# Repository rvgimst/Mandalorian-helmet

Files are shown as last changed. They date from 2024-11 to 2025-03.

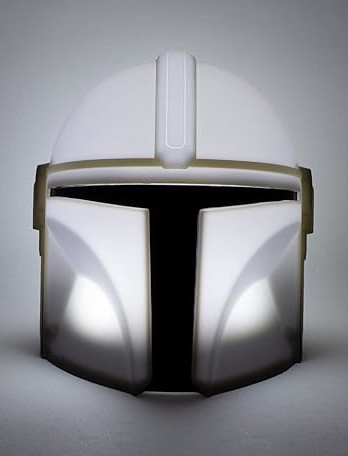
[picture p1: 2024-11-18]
pics/Mando helmet light on.jpg

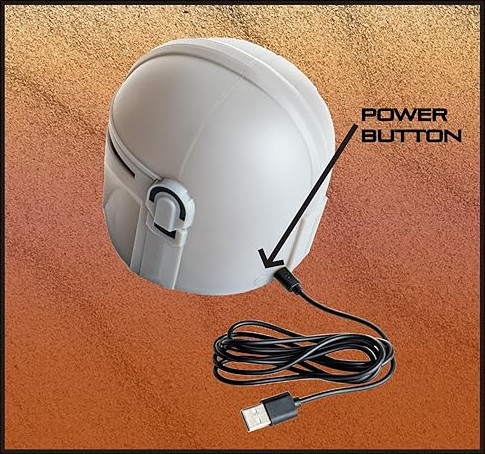
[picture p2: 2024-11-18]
pics/Mando helmet back.jpg

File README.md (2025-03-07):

# Mandalorian-helmet
Project to create a 3D printed mano helmet and add sounds and lights to it using Arduino with LEDs

Used ideas and files from:
https://www.myminifactory.com/object/3d-print-mandalorian-helmet-v2-106137

https://all3dp.com/2/3d-printed-mandalorian-helmet-3d-models/

Note on hardware I used:
========================
I used an Arduino Nano Every which worked fine on the breadboard, powered through its micro-USB port and the 5V pin connected to the breadboard's power strip (Vin not used).
When soldered on a protoboard in the device, the Arduino is powered through the Vin pin (5V pin not used).
When trying to connect the micro-USB port to the PCs USB port for uploading the code to the Arduino, it didn't work. Turns out that the Arduino powers the Vin port (which powers the MP player and all other components) and that it fails the PC to even recognize the Arduino. When ALSO powered through the power input of the device (Mando helmet), uploading worked!

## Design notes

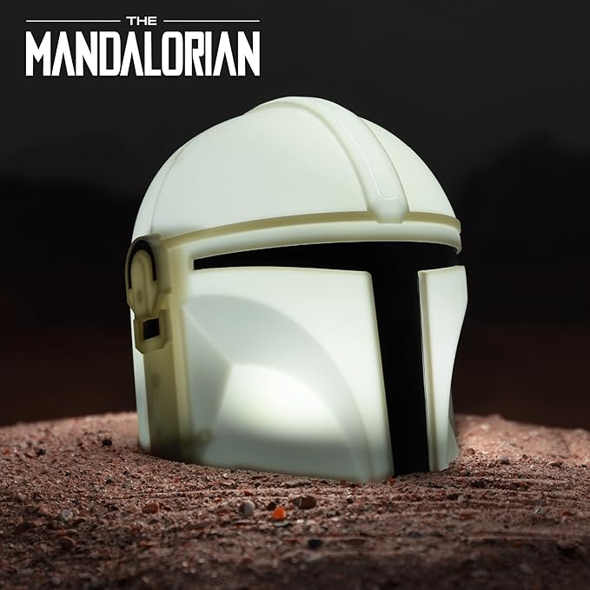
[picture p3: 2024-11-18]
pics/The Mandalorian Helmet Light.jpg

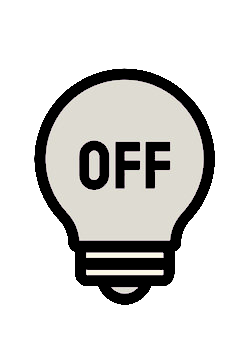
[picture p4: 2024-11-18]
pics/lamp off1.png

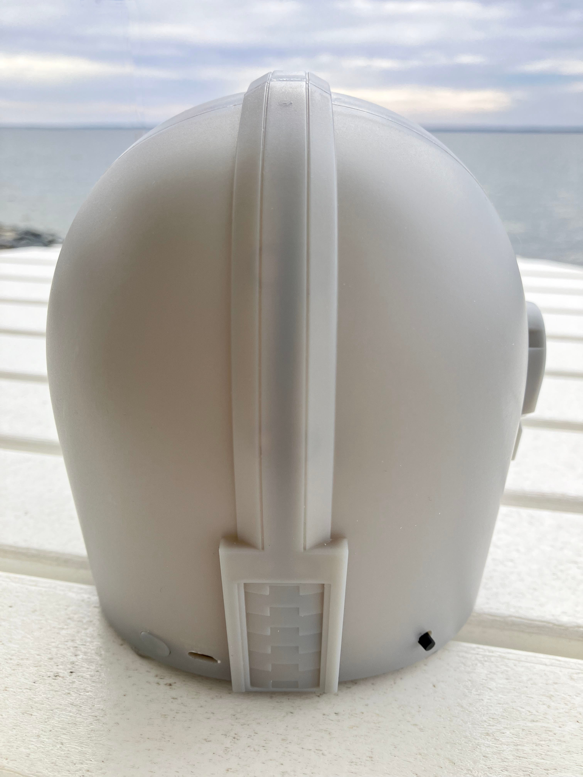
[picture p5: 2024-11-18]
pics/mando helmet rear.jpg

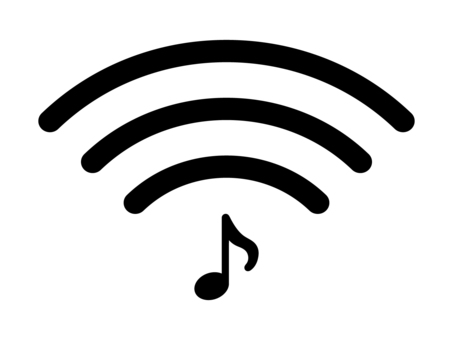
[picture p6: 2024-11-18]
pics/soundwave.jpeg

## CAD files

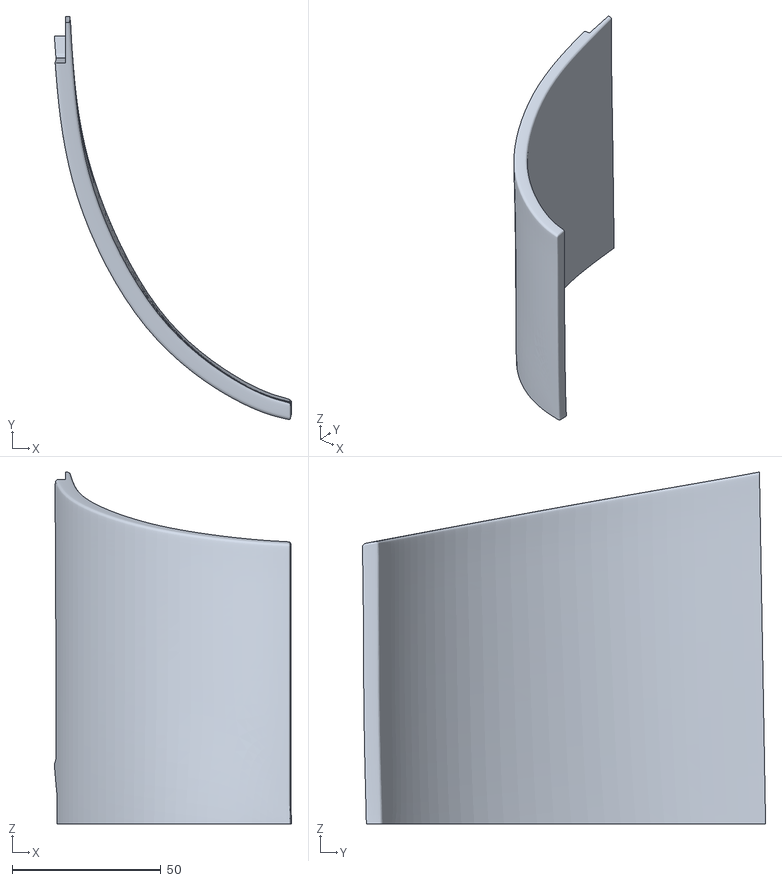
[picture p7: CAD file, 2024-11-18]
Mando helmet/helmet-8-piece-right-back-bottom.stl
79.9 x 135.7 x 118.5

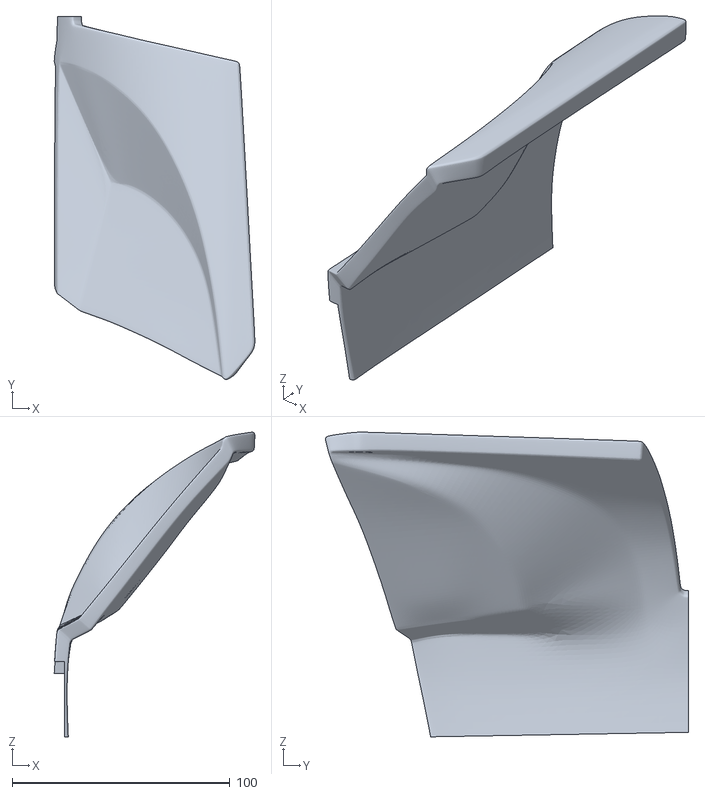
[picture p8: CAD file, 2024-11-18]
Mando helmet/helmet-8-piece-right-front-bottom.stl
92.2 x 166.8 x 140.0

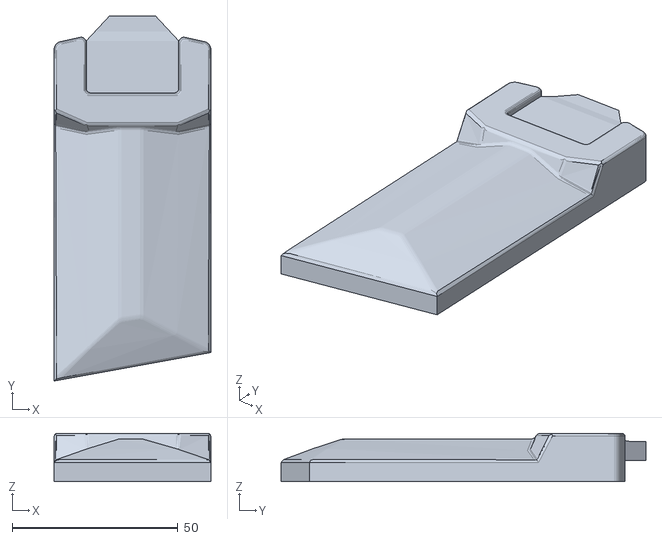
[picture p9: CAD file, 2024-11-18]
Mando helmet/ear-left-bottom.stl
47.3 x 110.2 x 14.6

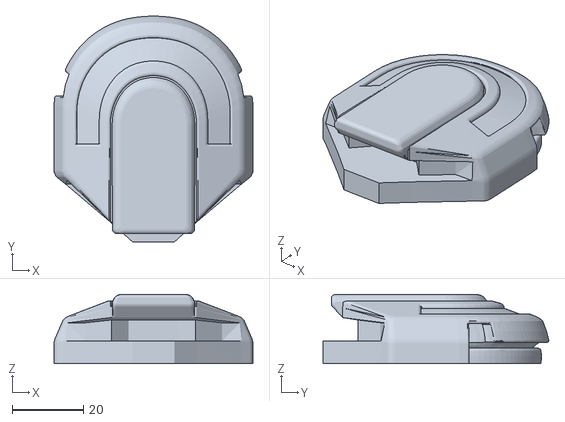
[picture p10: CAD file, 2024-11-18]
Mando helmet/ear-right-top.stl
56.0 x 63.5 x 19.5

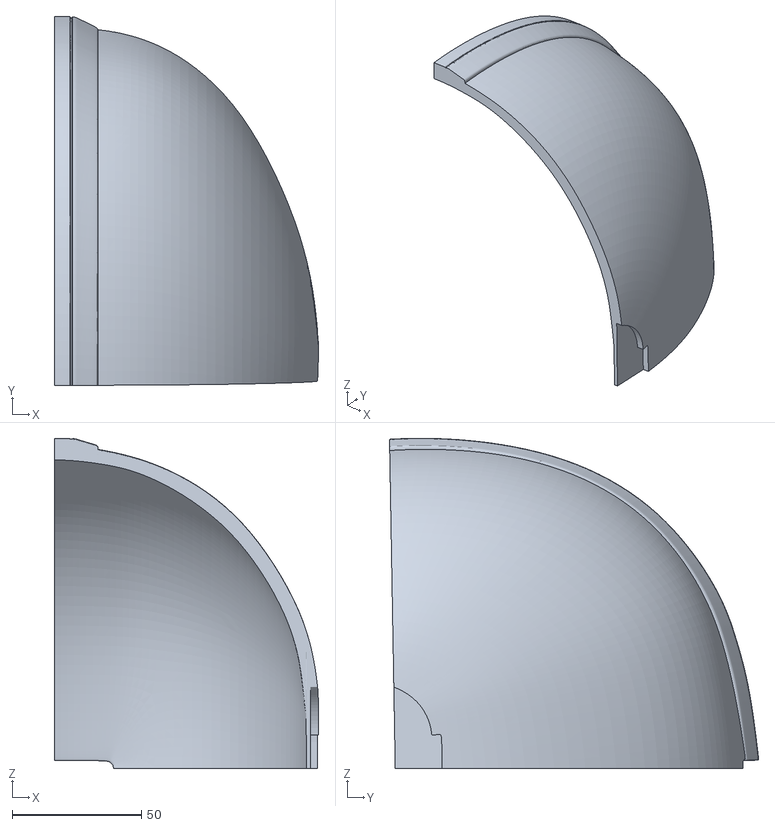
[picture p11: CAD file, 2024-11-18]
Mando helmet/helmet-8-piece-left-back-top.stl
102.3 x 142.7 x 127.8

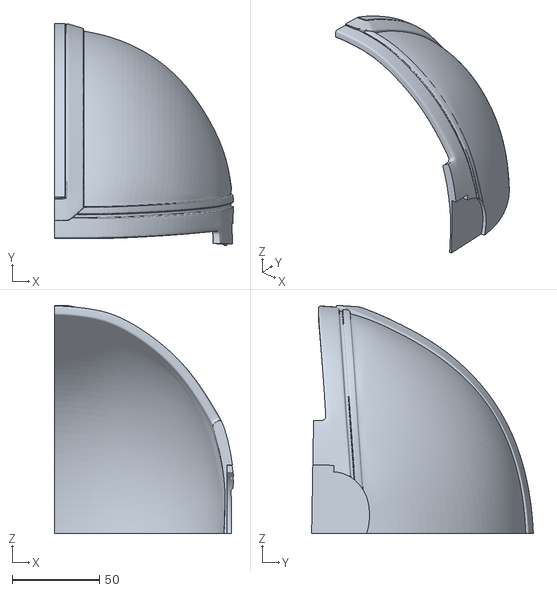
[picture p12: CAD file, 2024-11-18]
Mando helmet/helmet-8-piece-left-front-top.stl
103.0 x 127.4 x 131.0

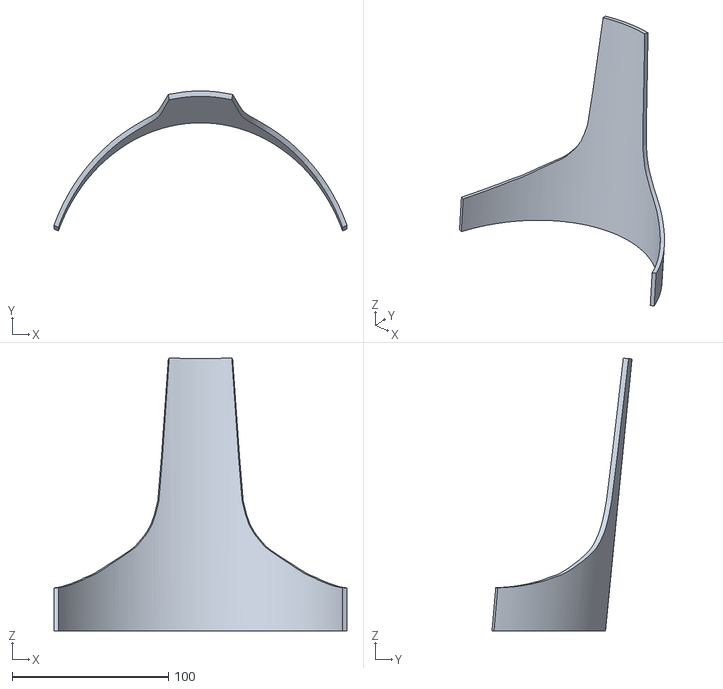
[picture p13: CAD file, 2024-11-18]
Mando helmet/visor.stl
187.6 x 89.7 x 174.7

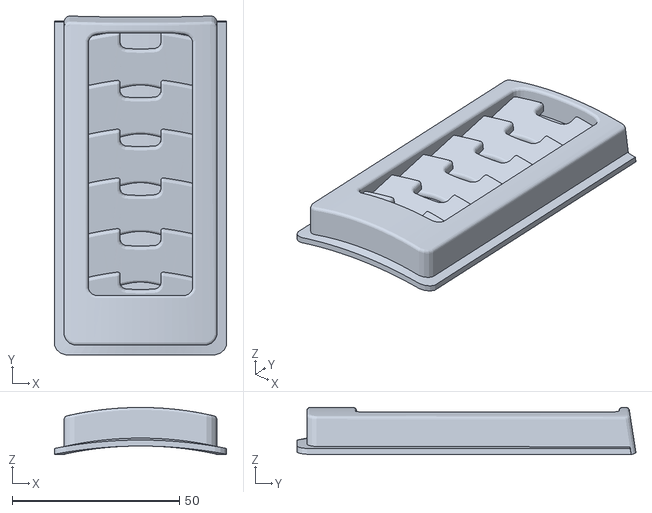
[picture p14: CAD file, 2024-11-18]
Mando helmet/vent.stl
51.4 x 101.2 x 14.0

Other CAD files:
Mando helmet/helmet-8-piece-left-front-bottom.stl
Mando helmet/helmet-8-piece-left-back-bottom.stl
Mando helmet/ear-left-top.stl
Mando helmet/helmet-8-piece-right-front-top.stl
Mando helmet/ear-right-bottom.stl
Mando helmet/helmet-8-piece-right-back-top.stl

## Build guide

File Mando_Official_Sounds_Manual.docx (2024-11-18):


# The Mandalorian Desktop Light

With Official Sounds

# Connecting

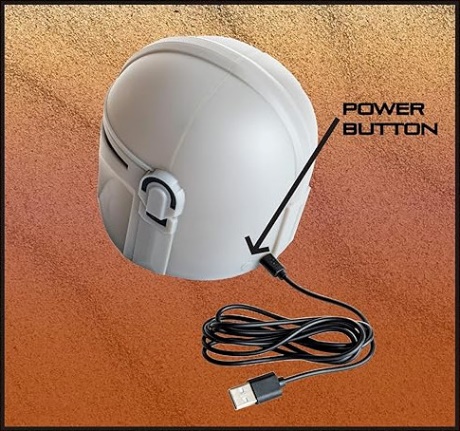
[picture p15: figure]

Micro USB port

5V DC 500mA

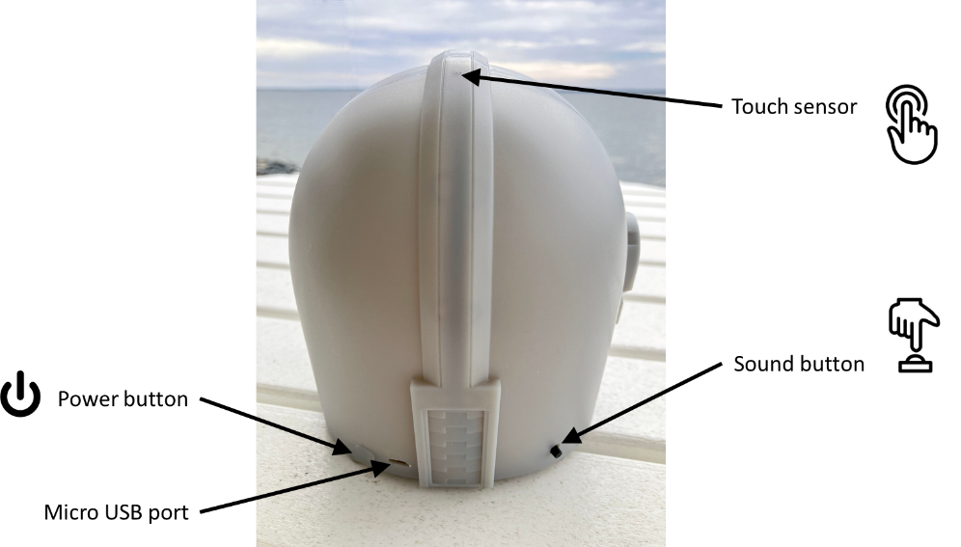
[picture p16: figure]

# Mando Helmet Interface

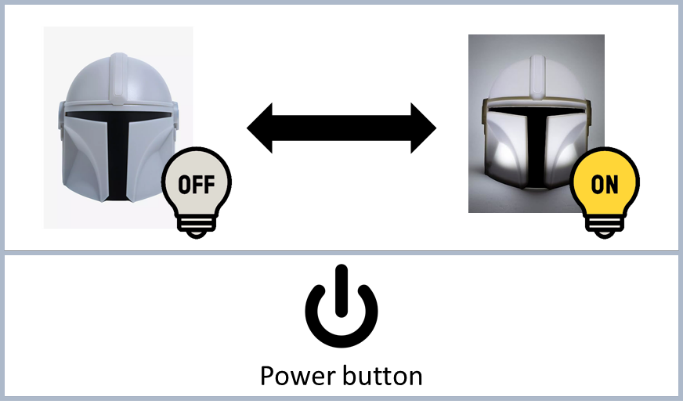
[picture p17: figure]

# Light Controls

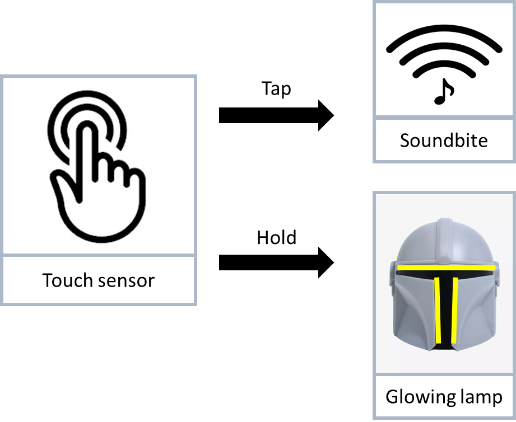
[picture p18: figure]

# Sound Controls

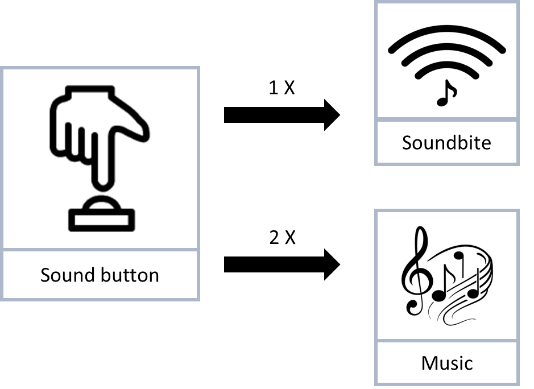
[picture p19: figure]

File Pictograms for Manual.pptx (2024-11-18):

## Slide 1


Micro USB port
5V DC 500mA

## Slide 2

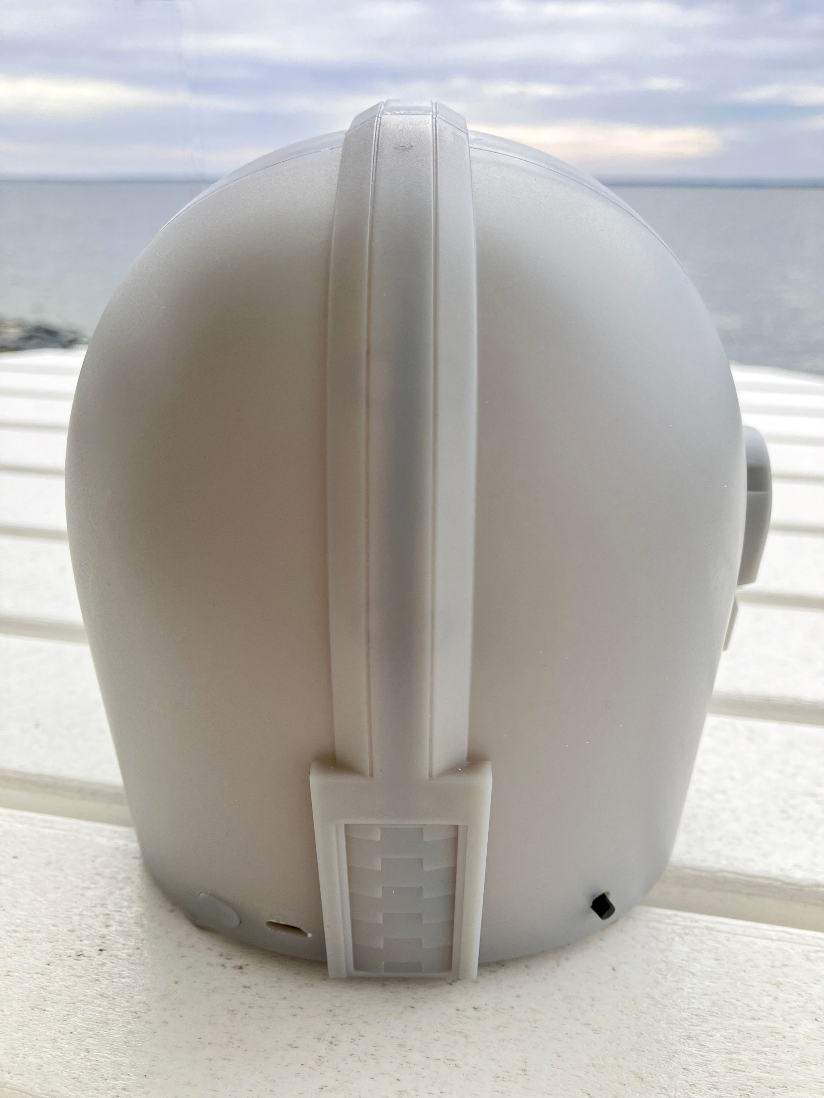
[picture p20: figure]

Touch sensor

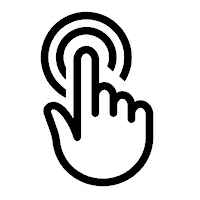
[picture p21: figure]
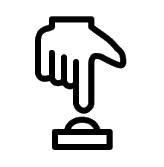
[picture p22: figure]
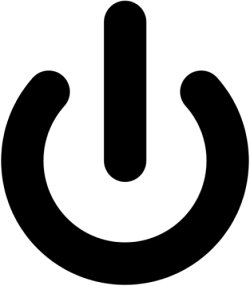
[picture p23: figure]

Power button

Sound button

Micro USB port

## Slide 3

Power button

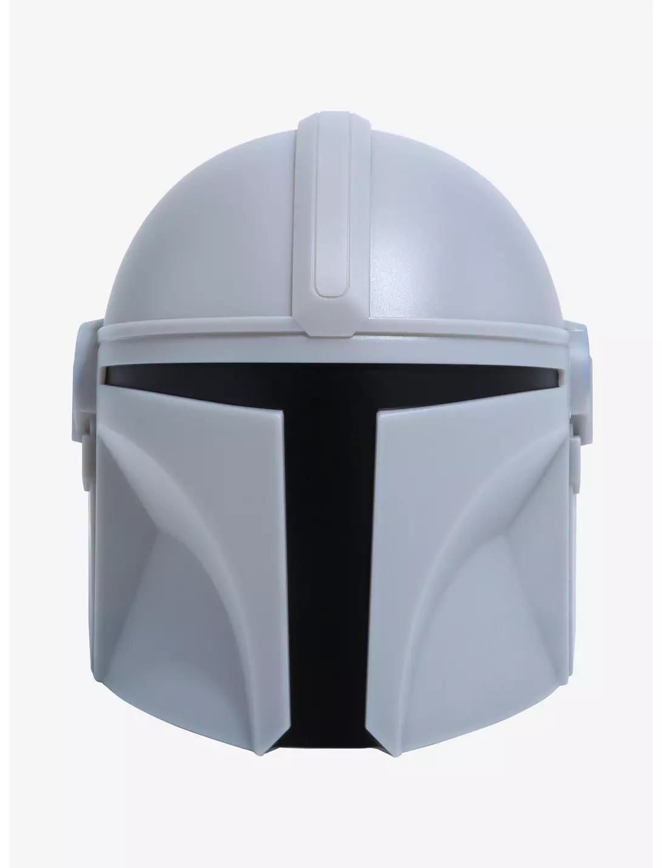
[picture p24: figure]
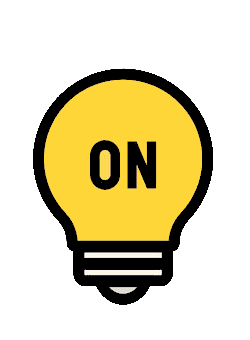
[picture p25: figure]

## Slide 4

Soundbite


Touch sensor

Tap

Hold

Glowing lamp

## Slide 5

Soundbite

Sound button

1 X

2 X

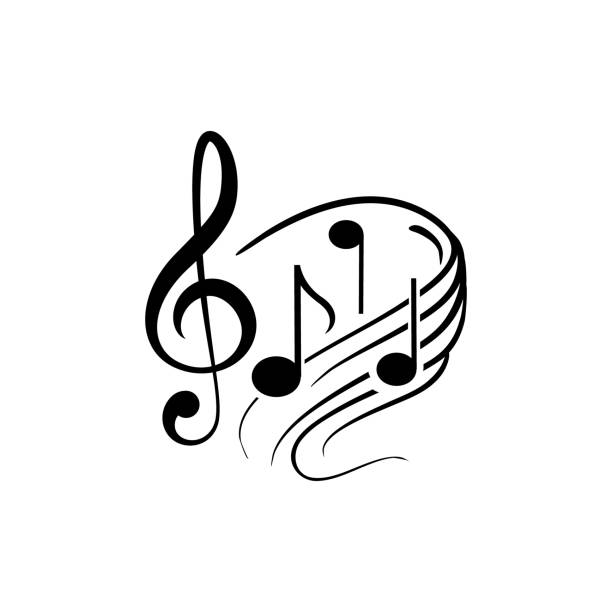
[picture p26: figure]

Music

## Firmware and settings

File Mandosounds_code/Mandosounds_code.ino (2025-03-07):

#include "DFPlayerMini_Fast.h"
#include <FastLED.h>

#define NUM_LEDS 45 // Kjell:44 Fred:45
#define DATA_PIN A0
#define LED_TYPE WS2811
#define COLOR_ORDER GRB
#define BRIGHTNESS 70
#define LED_INTRO_TIMEOUT     2000
#define LED_SOUNDBITE_TIMEOUT 5700
#define LED_ONELINER_TIMEOUT  3000
#define LED_THEME_TIMEOUT   198000 // (3*60 + 18)*1000

#define BUTTON_PIN 2
#define TOUCH_PIN 12 
#define LED_BUILTIN 13

// fixed folders with specific mp3 files
#define FOLDER_INTROS     1
#define FOLDER_SOUNDBITES 2
#define FOLDER_ONELINERS  3
#define FOLDER_THEME      4

#define VOLUME_DEFAULT 20
#define VOLUME_MUSIC 26
#if !defined(UBRR1H)
#include <SoftwareSerial.h>
SoftwareSerial mySerial(10, 11); // RX, TX
#endif

// touch input struct
struct Touch { 
	 byte wasPressed = LOW; 
	 byte isPressed = LOW; 
}; 

// states of the Mando helmet
#define STATE_NONE  0
#define STATE_SOUND 1
#define STATE_LAMP  2

// Global variables
CRGB leds[NUM_LEDS];
uint8_t paletteIndex = 0;
unsigned long ledTimeout[5] = {0, LED_INTRO_TIMEOUT, LED_SOUNDBITE_TIMEOUT, LED_ONELINER_TIMEOUT, LED_THEME_TIMEOUT};

bool once = true;
byte lastButtonState; // init in Setup()
unsigned long debounceDuration = 50; // millis
unsigned long lastTimeButtonStateChanged = 0;
enum { btnNone, btnSingleClick, btnDoubleClick, btnLongPress };

DFPlayerMini_Fast myMP3; // our mp3 player
byte folderCnt[5] = {0, 5, 8, 103, 1}; // hard coded for now, Mando: {0, 5, 8, 108, 1} StarWarsGeneric: {0, 5, 8, 103, 1}
String folderName[5] = {"root", "intros", "soundbites", "oneliners", "theme"};
byte soundLastPlayed[5] = {0, 0, 0, 0, 0}; // keep track of which sound was last played per folder (to prevent playing same sounds)
byte oneLinerCycle = 5; // after this number of one-liners we play a soundbite
int lastTypePlaying = 0; // FOLDER_INTRO | FOLDER_SOUNDBITES | FOLDER_ONELINERS
unsigned long lastTimePlayStart = 0; // time when last sound was started - for LED duration

Touch touch;

byte mandoState = STATE_NONE;

// Gradient palette "Sunset_Real_gp", originally from
// http://soliton.vm.bytemark.co.uk/pub/cpt-city/nd/atmospheric/tn/Sunset_Real.png.index.html
// converted for FastLED with gammas (2.6, 2.2, 2.5)
// Size: 28 bytes of program space.
DEFINE_GRADIENT_PALETTE( Sunset_Real_gp ) {
    0, 120,  0,  0,
   22, 179, 22,  0,
   51, 255,104,  0,
   85, 167, 22, 18,
  135, 100,  0,103,
  198,  16,  0,130,
  255,   0,  0,160};
  
CRGBPalette16 myPal = Sunset_Real_gp;

void setup() {
  Serial.begin(9600);

  pinMode(LED_BUILTIN, OUTPUT);
  pinMode(BUTTON_PIN, INPUT_PULLUP);
  pinMode(TOUCH_PIN, INPUT);
  lastButtonState = digitalRead(BUTTON_PIN);

  randomSeed(analogRead(A1));

#if !defined(UBRR1H)
  mySerial.begin(9600);
  myMP3.begin(mySerial/*, true*/);
#else
  Serial1.begin(9600);
  myMP3.begin(Serial1, true);
#endif

  // Init LED strip
  FastLED.addLeds<LED_TYPE, DATA_PIN, COLOR_ORDER>(leds, NUM_LEDS);
  FastLED.setBrightness(BRIGHTNESS); // set master brightness control
  FastLED.setMaxPowerInVoltsAndMilliamps(5, 500);
  FastLED.clear();
  
  Serial.print("Setting volume to ");
  Serial.println(VOLUME_DEFAULT);
  myMP3.volume(VOLUME_DEFAULT);

//  Serial.println((String)myMP3.numTracksInFolder(2)+" tracks found in folder 2");
  delay(2000);
}

// prevents same sound being played twice
long RandomDifferentFromPrevious(int folder) {
  long retval;

  if (folderCnt[folder] <= 1) return 0; // prevent endless loop

  while ((retval = random(folderCnt[folder])) == soundLastPlayed[folder]);
  Serial.println((String)"folder="+folder+" random="+retval+" prev="+soundLastPlayed[folder]); 
  soundLastPlayed[folder] = retval;
  return retval;
}

void playFromFolder(int folder) {
  mandoState = STATE_SOUND;
  int playTrack = RandomDifferentFromPrevious(folder)+1;
  lastTypePlaying = folder;
  lastTimePlayStart = millis();
  // Serial.println((String)myMP3.numTracksInFolder(folder)+" tracks found in folder "+folder+" ("+folderName[folder]+")");
  Serial.println((String)"Playing track "+playTrack+" from folder "+folder+" ("+folderName[folder]+")");
  Serial.println((String)"LEDtimeout= "+ledTimeout[folder]+"ms");
  myMP3.playFolder(folder, playTrack);
}
  
void playNextSound() {
  static byte oneLinersPlayed = 0;
  
  // for (int i=0; i<=5; i++) {
  //   Serial.println((String)myMP3.numTracksInFolder(i)+" tracks found in folder "+i); //+" ("+folderName[i]+")");
  //   delay(50);
  // }

  if (oneLinersPlayed == oneLinerCycle) {
    myMP3.volume(VOLUME_MUSIC);
    playFromFolder(FOLDER_SOUNDBITES);
    oneLinersPlayed = 0;
  } else {
    myMP3.volume(VOLUME_DEFAULT);
    playFromFolder(FOLDER_ONELINERS);
    oneLinersPlayed++;
  }
}

void showLEDEffect() {
  // create a sine wave with period of 2 sec (30bpm) to change brightness of the strip
  // beatsin8(bpm, minvalue, maxvalue, phase offset, timebase
  uint8_t sinBeat = beatsin8(41, 30, 255, 0, 0);
    // Serial.println((String)"LEDs: time passed since PlayStart= "+timePassed);

    // CRGB ColorFromPalette( const CRGBPalette16& pal,
    //                     uint8_t index,
    //                     uint8_t brightness=255,
    //                     TBlendType blendType=LINE
  EVERY_N_MILLISECONDS(20) {
    for (int i=0; i<NUM_LEDS; i++) {
      leds[i] = ColorFromPalette(myPal, paletteIndex, sinBeat, LINEARBLEND);
    }
    paletteIndex++; // loops over 255 for the type is uint8_t
  }

    // // MOVING PALETTE EFFECT
    // //fill_palette(led array, nLEDS, startIndex, indexDelta, palette,
    // //             brightness, blendType:LINEARBLEND|NOBLEND)
    // fill_palette(leds, NUM_LEDS, paletteIndex, 1 /*255/NUM_LEDS*/, myPal, BRIGHTNESS, LINEARBLEND);
  
    // EVERY_N_MILLISECONDS(20) {
    //   paletteIndex++;
    // }
}

void showLampEffect() {
    // CRGB ColorFromPalette( const CRGBPalette16& pal,
    //                     uint8_t index,
    //                     uint8_t brightness=255,
    //                     TBlendType blendType=LINE
  EVERY_N_MILLISECONDS(200) {
    for (int i=0; i<NUM_LEDS; i++) {
      leds[i] = ColorFromPalette(myPal, paletteIndex, BRIGHTNESS, LINEARBLEND);
    }
    paletteIndex++; // loops over 255 for the type is uint8_t
  }
}

int chkTouch() {
  int retVal = btnNone;
  const  unsigned long LongPressTimeout = 1000;
  static unsigned long msecLast = 0;
         unsigned long msec = millis ();

  //TODO: double touch
  touch.isPressed = (digitalRead(TOUCH_PIN) == HIGH);

  if (touch.wasPressed && !touch.isPressed) { // change to release
    Serial.println("Touch released");
    if (msec - msecLast < LongPressTimeout) { // click only when short press
      retVal = btnSingleClick;
    }
  }
  else if (!touch.wasPressed && touch.isPressed) { // change to press
    Serial.println("Touch pressed");
    msecLast = msec;
  }
  else if (touch.wasPressed && touch.isPressed) { // holding
    if (msecLast != 0 && msec - msecLast >= LongPressTimeout) { // long press
      retVal = btnLongPress;
      msecLast = 0;
    }
  }
  touch.wasPressed = touch.isPressed;
  
  return retVal;
}

int chkButton() {
  const  unsigned long ButTimeout  = 250;
  static unsigned long msecLast;
         unsigned long msec = millis ();

  if (msecLast && (msec - msecLast) > ButTimeout)  {
    msecLast = 0;
    return btnSingleClick;
  }

  if (millis() - lastTimeButtonStateChanged > debounceDuration) {
    byte buttonState = digitalRead(BUTTON_PIN);
    if (lastButtonState != buttonState) {
      lastTimeButtonStateChanged = millis();
      lastButtonState = buttonState;

      if (LOW == buttonState)  {   // press
        if (msecLast)  { // 2nd press
          msecLast = 0;
          return btnDoubleClick;
        }
        else
          msecLast = (0 == msec ? 1 : msec);
      }
    }
  }

  return btnNone;

  // if (millis() - lastTimeButtonStateChanged > debounceDuration) {
  //   byte buttonState = digitalRead(BUTTON_PIN);
    
  //   if (buttonState != lastButtonState) {
  //     Serial.println("Button state changed");
  //     lastTimeButtonStateChanged = millis();
  //     lastButtonState = buttonState;
  //     if (buttonState == LOW) {
  //       // Button is pushed down. We play another random sound
  //       Serial.println("Button pushed");
  //       playNextSound();
  //     }
  //   }
  // }

}

void loop() {
  static unsigned long timePassed = 0;

  // play random track at startup
  if (once) {
    Serial.println("Playing startup sound");
    myMP3.volume(VOLUME_DEFAULT);
    playFromFolder(FOLDER_INTROS);
    once = false;
  }
  
  // BUTTON TRIGGER
  switch(chkButton()) {
    case btnSingleClick:
      Serial.println("SINGLE button click (Push)");
      myMP3.volume(VOLUME_DEFAULT);
      playNextSound();
      break;
    case btnDoubleClick:
      Serial.println("DOUBLE button click (Push)");
      myMP3.volume(20);
      playFromFolder(FOLDER_THEME);    
      break;
  }

  // TOUCH TRIGGER
  switch(chkTouch()) {
    case btnSingleClick:
      Serial.println("SINGLE button click (Push)");
      myMP3.volume(VOLUME_DEFAULT);
      playNextSound();
      break;
    case btnLongPress:
      Serial.println("LONG button Press");
      // toggle lamp mode on/off
      mandoState = STATE_LAMP == mandoState ? STATE_NONE : STATE_LAMP;
      break;
  }

  switch(mandoState) {
    case STATE_SOUND:
      timePassed = millis() - lastTimePlayStart;
      if (timePassed < ledTimeout[lastTypePlaying]) { // estimate while sound is playing
        showLEDEffect();
      }
      else {
        mandoState = STATE_NONE;
      }
      break;
    case STATE_LAMP:
      // LED Lamp effect, no sound
      showLampEffect();
      
      // FOR TESTING: Or play theme with LED effects
      // myMP3.volume(20);
      // playFromFolder(FOLDER_THEME);      
      break;
    default:
      break;
  }

  if (mandoState == STATE_NONE) {
    EVERY_N_MILLISECONDS(5) {
      fadeToBlackBy(leds, NUM_LEDS, 1);
    }
    //FastLED.clear();
  }

  FastLED.show();
}

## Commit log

2024-11-18 First version of 3D print files from site mentioned in README.md
    [ear-left-bottom.stl, ear-left-top.stl, ear-right-bottom.stl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]
2024-11-18 Mando sound and LED code
    added docu for DFPlayer pinout
2025-02-15 Added Star Wars sounds
    added function in code to prevent replaying sounds per folder twice
    changed folder count for Star Wars sounds (kept the Mando numbers in comments)
    [Mandosounds_code.ino]
2025-03-07 added 1 LED in array for second project
2025-03-07 Added note for uploading code to Arduino Every with soldered board
